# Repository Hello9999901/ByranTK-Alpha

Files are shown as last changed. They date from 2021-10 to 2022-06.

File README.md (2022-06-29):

# ByranTK-Alpha

# Note: New 3D Printed Version of the case added! First prototype working!!

*The ByranTK-Alpha is an 80 key custom mechanical keyboard, designed to be made with any material.*
<br>
<br>
*"All the keys you need and no more."*

### V1.1 is confirmed to be working with firmware from https://github.com/Hello9999901/zmk-config-btk-alpha

# What is it:
The ByranTK-Alpha is an ongoing open-source keyboard project. It is extremely simple and utilizes a nice!nano from Nice Keyboards as the MCU. The battery life is estimated to be around 3 months of continuous usage (varies extremely depending on battery capacity, tested with 500mah battery from Adafruit). The keyboard is designed in KiCAD and FreeCAD, with the renders made with Blender.

# Features:
 - ZMK Firmware
 - Pro Micro Form Factor *
 - Wireless First Design
 - Split Spacebar
 - Low Profile (relative to other keyboards)
 - Hotswap Sockets
 - South facing (supports cherry profile)
 - Exploded 75% (ish) layout
 - Highly Customizable

# Why?
Because nobody has done such thing yet. I have always wanted a simple-looking, customizable (software-wise and hardware-wise), exploded 75% layout keyboard. In addition, it had to be under a certain price point. I estimate for it to cost less than 100 dollars for all the parts and all the machining, though that is subject to change. If you want CNC alu, then that'll cost you a couple cold hard Benjamins (tldr; a lot).

# Image Gallery
(subject to change as design alters)
<div style="display: flex;">
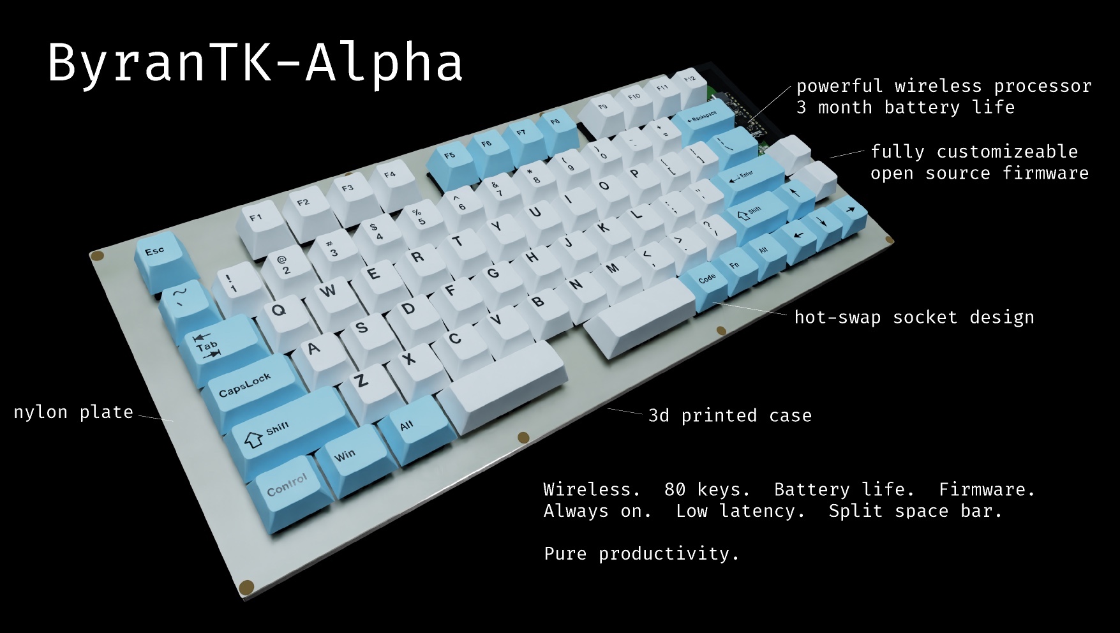
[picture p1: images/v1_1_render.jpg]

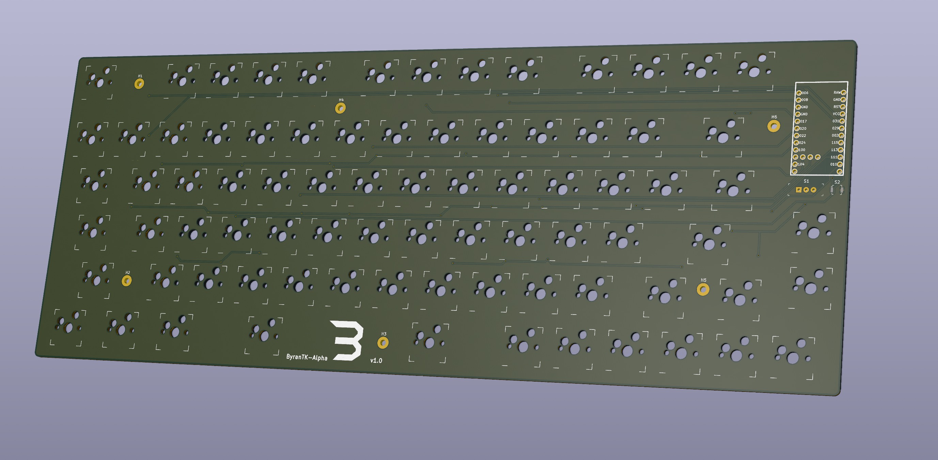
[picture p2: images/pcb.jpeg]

</div>

# Build Guide
### This build guide is very vague and will be improved on in the near future
### Parts:
> Note that these part links are only for reference. Some products can be found for cheaper (especially the hotswap sockets).

> The SPDT and SPST switches have specific footprints that match on the board. You can alter them if they're out of stock.

> You don't need to buy diodes if you are using SMT assembly. I used JLCPCB.
  - PCB
  - [Kailh Hotswap Sockets](https://shop.keyboard.io/products/kailh-hotswap-sockets-for-mx-style-keyswitches-x-25)
  - [Diodes (1N4148 SMT SOD-123)](https://www.adafruit.com/product/5099)
  - [SPDT Switch](https://www.adafruit.com/product/805)
  - [Battery (can be different capacity) with JST-PH 2 Pin Header](https://www.adafruit.com/product/1578)
  - [SPST Switch](https://www.adafruit.com/product/1489)
  - [JST-PH Right Angle Connector](https://www.adafruit.com/product/1769)
  - [Swiss Socket Headers (Female)](https://www.adafruit.com/product/3646)
  - [Swiss Socket Headers (Male)](https://www.adafruit.com/product/3647)

1. Order all the parts
   - I ordered everything off of JLCPCB, with SMT assembly for the diodes because I'm lazy. The pick and place/bom files are in the bom folder, ready for upload to JLCPCB. It is highly suggested you use SMT assembly because it is extremely cheap and saves a lot of time.
   - Apparantly, you can also get smt hotswap sockets assembled too, though I did not do that.
2. Solder it all together
   - Solder on the hotswap sockets and the nice!nano. This will take a while (perhaps an hour or two) depending on your soldering experience. Note that if you choose not to use SMT assembly on the PCB, the diodes will be very hard to solder. I socketed the nice!nano using Swiss machine pins off of Adafruit.
3. Build and flash the firmware onto the nice!nano
   - Build the firmware and put the nice!nano into bootloader (DFU) mode (short GND and RST twice in rapid succession). Drag the UF2 file into the nice!nano "storage device". The firmware can be made with my zmk-config directory.
4. Laser cut the case or 3D print
   - This step is pretty self explanatory. It's a sandwich design, so lasercut many pieces and adhere them together. The plate must be 1.5mm (+- 0.1mm). The rest can be any height as long as when everything is stacked together, it is taller than 15mm, and the height between the bottom of the plate and the top of the bottom pice is taller than 12mm.
   - Alternatively, you can 3D print the case. I decided to 3D print because it was faster to prototype. 2 file types, one split and one full depending on your bed size. It also looks really cool.
5. Put everything together
   - Glue it, screw it together, I don't really know. I screwed into a 3D printed case with some screws found in a bin of hope. Just make sure the entire thing fits. If you're that type of person, the more FLeX the better. Nylon should get you that. Plug in the battery (you might need to switch the battery wiring to make sure the GND goes into GND and RAW goes into RAW). You don't need screws to hold the PCB and plate together; the hotswap sockets and the plate should hold itself together. Get some 5mm foam and put it as dampener under the PCB. Make sure to keep the battery isolated when dampening so it doesn't short/blow up.
6. Use it
   - You've made it! Congrats! Customize the keymap, change the case material, it's all up to you. That's the beauty of open source hardware and software. I hope you enjoy the ByranTK-Alpha.

# License
Unless stated otherwise, the parts are licensed under the MIT License. Parts that are identified as (GPL) are licensed under the GPLv3 License.

\* The nice!nano v2 is used in this design. It has 3 extra pins in the center of the PCB, two of which the ByranTK-Alpha utilizes

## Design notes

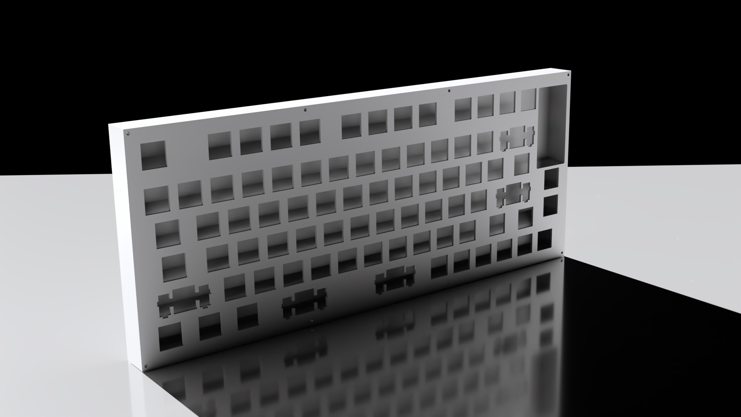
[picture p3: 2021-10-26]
images/case.jpeg

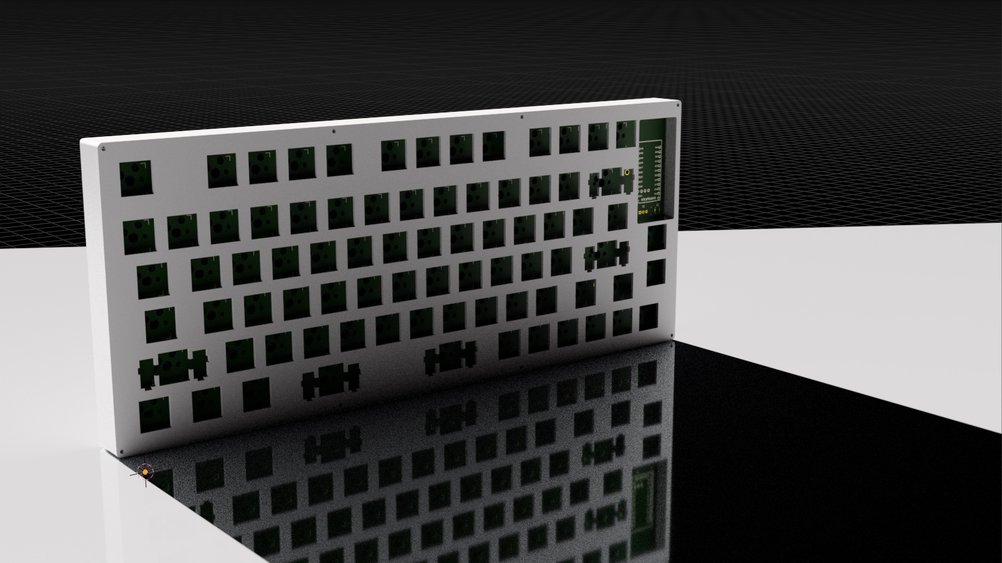
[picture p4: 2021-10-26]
images/caseWpcb.jpeg

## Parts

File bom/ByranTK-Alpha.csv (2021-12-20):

Comment | Designator | Footprint | LCSC
Battery | BT1
1N4148W | D1,D2,D3,D4,D5,D6,D7,D8,D9,D10,D11,D12,D13,D14,D15,D16,D17,D18,D19,D20,D21,D22,D23,D24,D25,D26,D27,D28,D29,D30,D31,D32,D33,D34,D35,D36,D37,D38,D39,D40,D41,D42,D43,D44,D45,D46,D47,D48,D49,D50,D51,D52,D53,D54,D55,D56,D57,D58,D59,D60,D61,D62,D63,D64,D65,D66,D67,D68,D69,D70,D71,D72,D73,D74,D75,D76,D77,D78,D79,D80 | Diode_SMD:D_SOD-123 | C81598
M2 Mounting_Hole | H1,H2,H3,H4,H5,H6 | MountingHole:MountingHole_2.2mm_M2_Pad_Via
JST-PH_SM4 | J1 | Connector_JST:JST_PH_S2B-PH-SM4-TB_1x02-1MP_P2.00mm_Horizontal
EG1218 | S1 | digikey-footprints:Switch_Slide_11.6x4mm_EG1218
6mm Slim Tactile Switch | S2 | Button_Switch_THT:SW_TH_Tactile_Omron_B3F-10xx
SW_Push | SW1,SW2,SW7,SW8,SW9,SW10,SW12,SW13,SW14,SW15,SW16,SW18,SW19,SW20,SW21,SW22,SW24,SW25,SW26,SW27,SW28,SW29,SW30,SW31,SW32,SW33,SW34,SW35,SW36,SW37,SW38,SW39,SW40,SW41,SW42,SW43,SW45,SW46,SW47,SW48,SW49,SW50,SW51,SW52,SW53,SW54,SW55,SW56,SW57,SW58,SW59,SW60,SW61,SW62,SW63,SW64,SW65,SW66,SW68,SW69,SW70,SW71,SW73,SW74,SW75,SW78,SW79,SW80 | MX_Only:MXOnly-1U-Hotswap
SW_Push | SW23,SW44 | MX_Only:MXOnly-2.75U-Hotswap
SW_Push | SW3,SW77 | MX_Only:MXOnly-1.5U-Hotswap
SW_Push | SW4,SW67 | MX_Only:MXOnly-1.75U-Hotswap
SW_Push | SW5,SW72 | MX_Only:MXOnly-2.25U-Hotswap
SW_Push | SW6,SW11,SW17 | MX_Only:MXOnly-1.25U-Hotswap
SW_Push | SW76 | MX_Only:MXOnly-2U-Hotswap
nice_nano | U1 | nice_nano:nice_nano

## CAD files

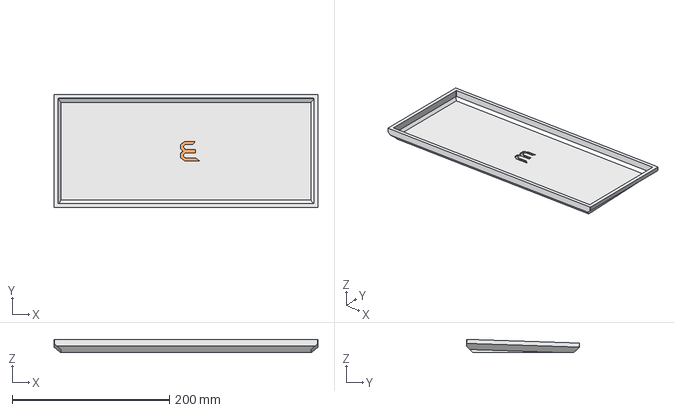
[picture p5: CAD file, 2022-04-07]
case/3D Print/Full Print.step
335.4 x 144.0 x 16.9 mm

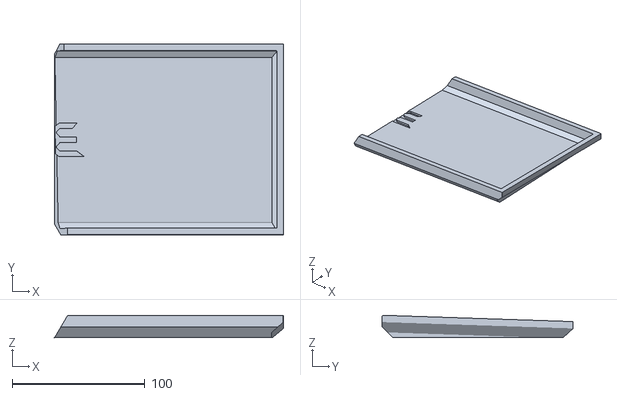
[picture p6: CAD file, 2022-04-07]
case/3D Print/Split Prints/cut_l.stl
172.5 x 144.0 x 16.9

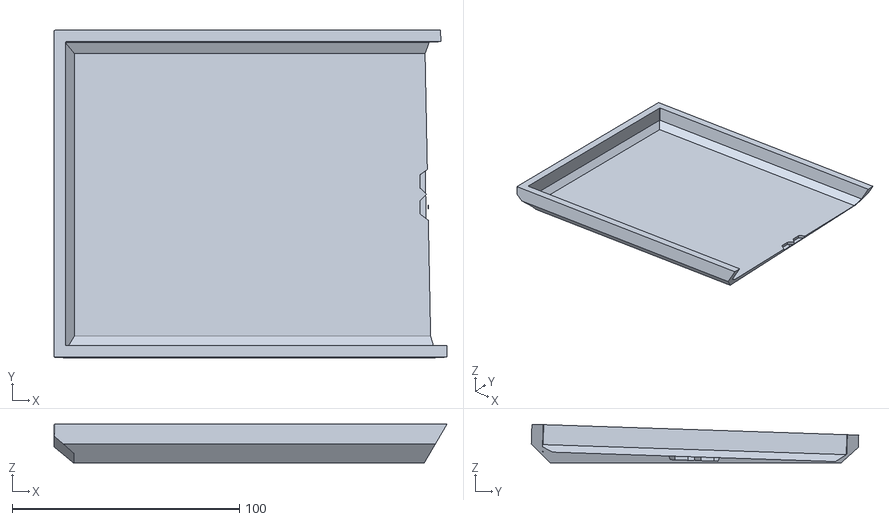
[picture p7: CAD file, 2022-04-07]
case/3D Print/Split Prints/cut_r.stl
172.8 x 144.0 x 16.9

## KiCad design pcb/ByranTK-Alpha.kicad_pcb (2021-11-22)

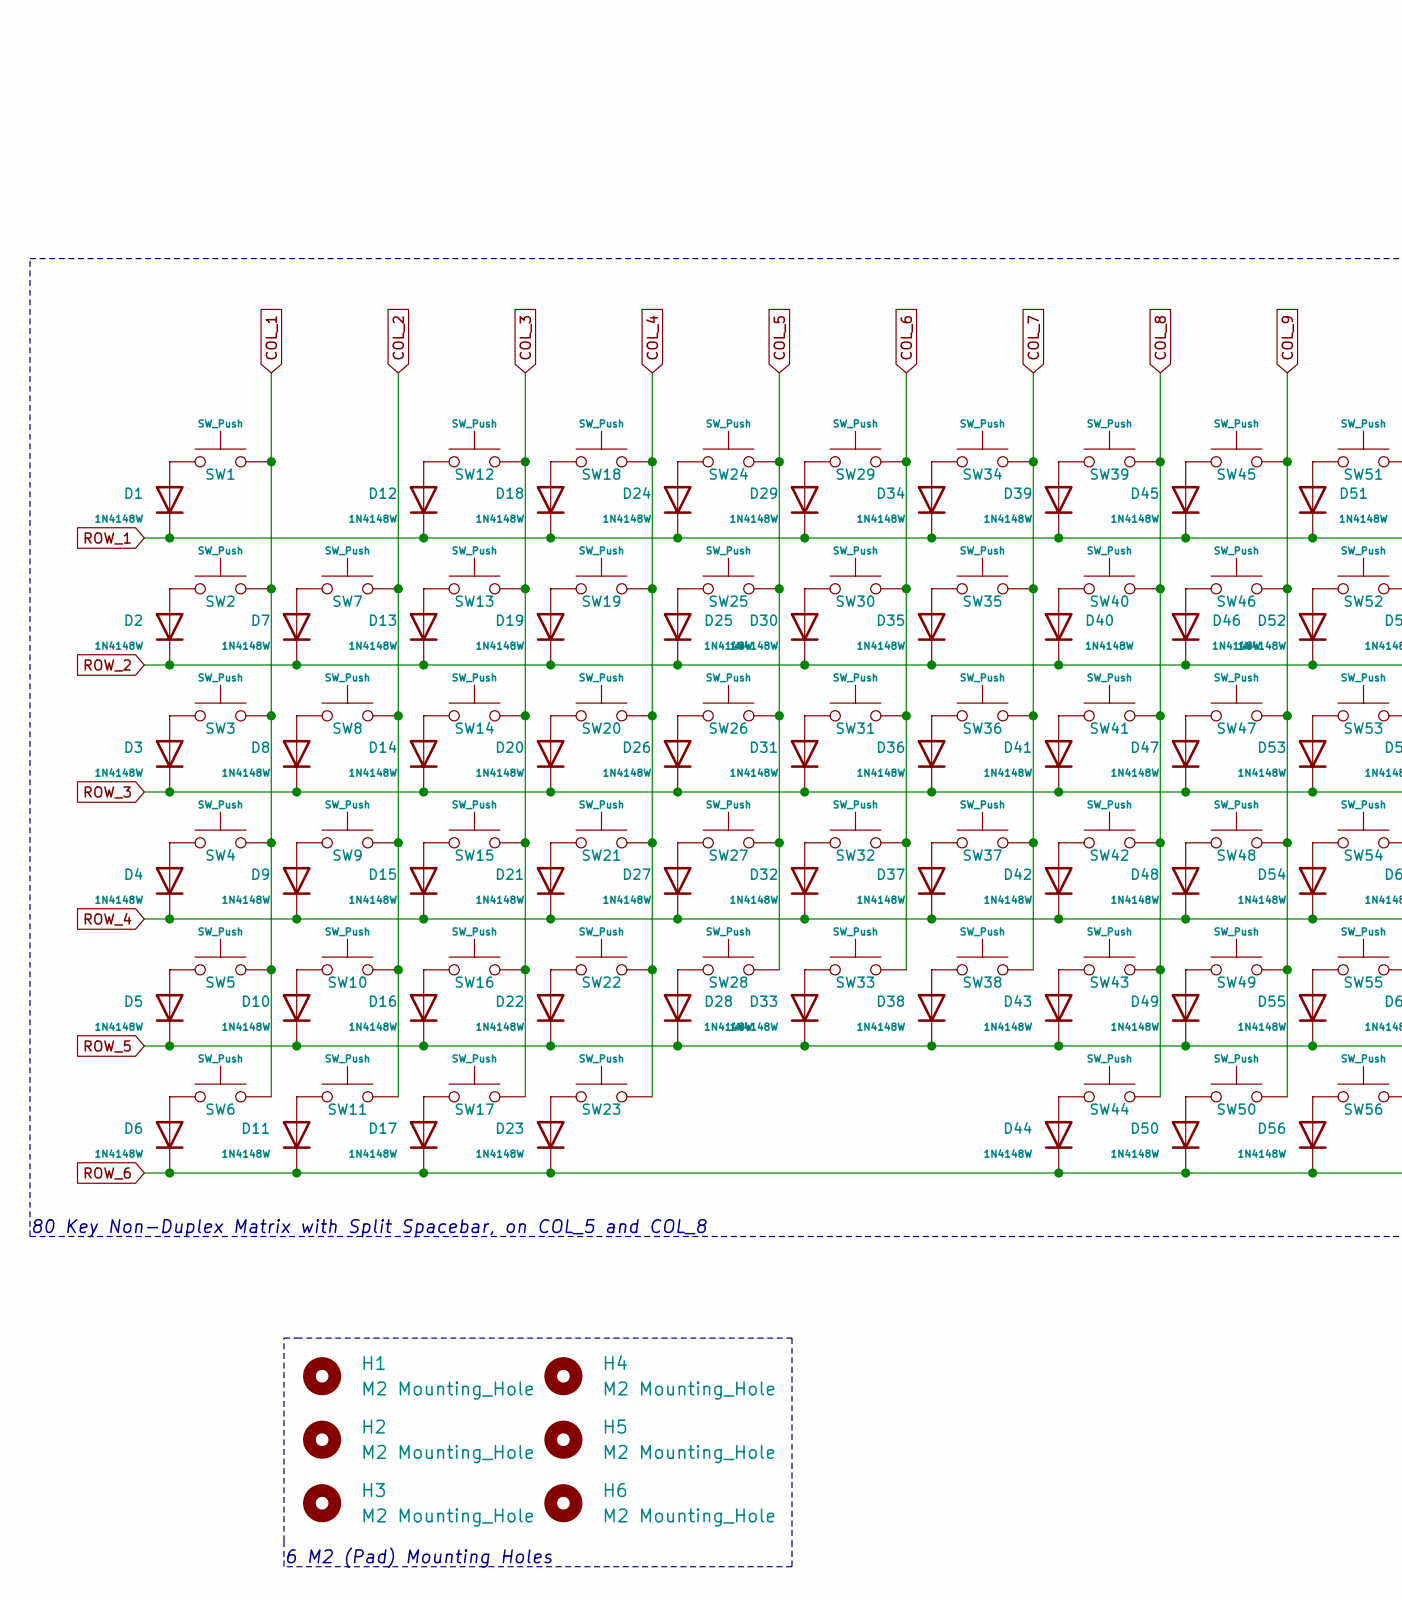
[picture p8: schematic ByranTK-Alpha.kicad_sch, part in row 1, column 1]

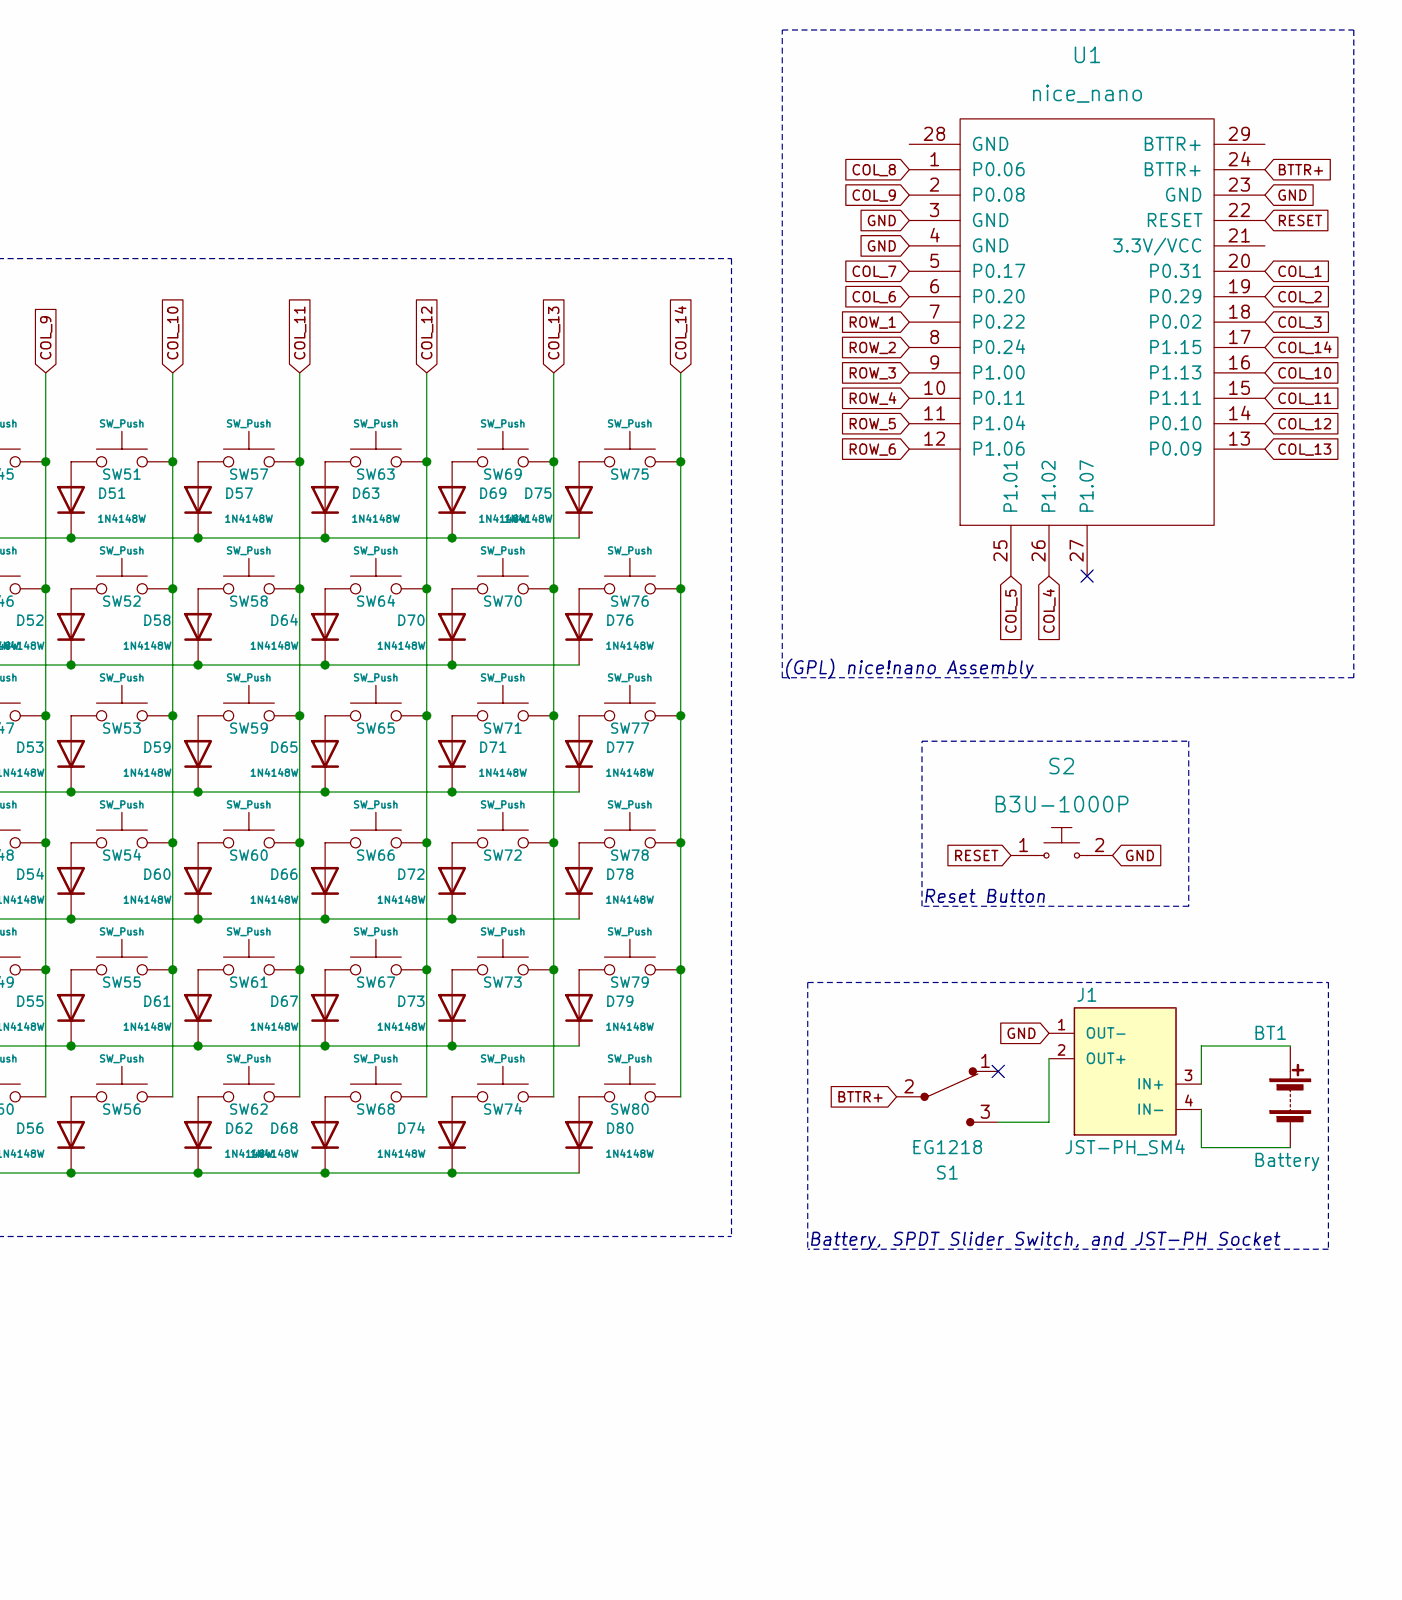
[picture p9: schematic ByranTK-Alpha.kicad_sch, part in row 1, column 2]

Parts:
BT1: Battery; ADAFRUIT_BAT_ID_1570_100mAh
D1, D2, D3, D4, D5, D6, D7, D8, D9, D10, D11, D12, D13, D14, D15, D16, D17, D18, D19, D20, D21, D22, D23, D24, D25, D26, D27, D28, D29, D30, D31, D32, D33, D34, D35, D36, D37, D38, D39, D40, D41, D42, D43, D44, D45, D46, D47, D48, D49, D50, D51, D52, D53, D54, D55, D56, D57, D58, D59, D60, D61, D62, D63, D64, D65, D66, D67, D68, D69, D70, D71, D72, D73, D74, D75, D76, D77, D78, D79, D80: 1N4148W; D_SOD-123
H1, H2, H3, H4, H5, H6: M2 Mounting_Hole; MountingHole_2.2mm_M2_Pad
J1: JST-PH_SM4; JST_PH_S2B-PH-SM4-TB_1x02-1MP_P2.00mm_Horizontal
S1: EG1218; Switch_Slide_11.6x4mm_EG1218; MPN EG1218; Digi-Key_PN EG1903-ND
S2: B3U-1000P; Switch_Tactile_SMD_B3U-1000P; MPN B3U-1000P; Digi-Key_PN SW1020CT-ND
SW1, SW2, SW7, SW8, SW9, SW10, SW12, SW13, SW14, SW15, SW16, SW18, SW19, SW20, SW21, SW22, SW24, SW25, SW26, SW27, SW28, SW29, SW30, SW31, SW32, SW33, SW34, SW35, SW36, SW37, SW38, SW39, SW40, SW41, SW42, SW43, SW45, SW46, SW47, SW48, SW49, SW50, SW51, SW52, SW53, SW54, SW55, SW56, SW57, SW58, SW59, SW60, SW61, SW62, SW63, SW64, SW65, SW66, SW68, SW69, SW70, SW71, SW73, SW74, SW75, SW78, SW79, SW80: SW_Push; MXOnly-1U-Hotswap
SW3, SW77: SW_Push; MXOnly-1.5U-Hotswap
SW4, SW67: SW_Push; MXOnly-1.75U-Hotswap
SW5, SW72: SW_Push; MXOnly-2.25U-Hotswap
SW6, SW11, SW17: SW_Push; MXOnly-1.25U-Hotswap
SW23, SW44: SW_Push; MXOnly-2.75U-Hotswap
SW76: SW_Push; MXOnly-2U-Hotswap
U1: nice_nano

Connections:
BTTR+: S1.2, U1.24 (BTTR+)
COL_1: SW1.2, SW2.2, SW3.2, SW4.2, SW5.2, SW6.2, U1.20 (P0.31)
COL_2: SW7.2, SW8.2, SW9.2, SW10.2, SW11.2, U1.19 (P0.29)
COL_3: SW12.2, SW13.2, SW14.2, SW15.2, SW16.2, SW17.2, U1.18 (P0.02)
COL_4: SW18.2, SW19.2, SW20.2, SW21.2, SW22.2, SW23.2, U1.26 (P1.02)
COL_5: SW24.2, SW25.2, SW26.2, SW27.2, SW28.2, U1.25 (P1.01)
COL_6: SW29.2, SW30.2, SW31.2, SW32.2, SW33.2, U1.6 (P0.20)
COL_7: SW34.2, SW35.2, SW36.2, SW37.2, SW38.2, U1.5 (P0.17)
COL_8: SW39.2, SW40.2, SW41.2, SW42.2, SW43.2, SW44.2, U1.1 (P0.06)
COL_9: SW45.2, SW46.2, SW47.2, SW48.2, SW49.2, SW50.2, U1.2 (P0.08)
COL_10: SW51.2, SW52.2, SW53.2, SW54.2, SW55.2, SW56.2, U1.16 (P1.13)
COL_11: SW57.2, SW58.2, SW59.2, SW60.2, SW61.2, SW62.2, U1.15 (P1.11)
COL_12: SW63.2, SW64.2, SW65.2, SW66.2, SW67.2, SW68.2, U1.14 (P0.10)
COL_13: SW69.2, SW70.2, SW71.2, SW72.2, SW73.2, SW74.2, U1.13 (P0.09)
COL_14: SW75.2, SW76.2, SW77.2, SW78.2, SW79.2, SW80.2, U1.17 (P1.15)
GND: J1.1 (OUT-), S2.2, U1.3 (GND), U1.4 (GND), U1.23 (GND)
unnamed: D1.2 (A), SW1.1
unnamed: D2.2 (A), SW2.1
unnamed: D3.2 (A), SW3.1
unnamed: D4.2 (A), SW4.1
unnamed: D5.2 (A), SW5.1
unnamed: D6.2 (A), SW6.1
unnamed: D7.2 (A), SW7.1
unnamed: D8.2 (A), SW8.1
unnamed: D9.2 (A), SW9.1
unnamed: D10.2 (A), SW10.1
unnamed: D11.2 (A), SW11.1
unnamed: D12.2 (A), SW12.1
unnamed: D13.2 (A), SW13.1
unnamed: D14.2 (A), SW14.1
unnamed: D15.2 (A), SW15.1
unnamed: D16.2 (A), SW16.1
unnamed: D17.2 (A), SW17.1
unnamed: D18.2 (A), SW18.1
unnamed: D19.2 (A), SW19.1
unnamed: D20.2 (A), SW20.1
unnamed: D21.2 (A), SW21.1
unnamed: D22.2 (A), SW22.1
unnamed: D23.2 (A), SW23.1
unnamed: D24.2 (A), SW24.1
unnamed: D25.2 (A), SW25.1
unnamed: D26.2 (A), SW26.1
unnamed: D27.2 (A), SW27.1
unnamed: D28.2 (A), SW28.1
unnamed: D29.2 (A), SW29.1
unnamed: D30.2 (A), SW30.1
unnamed: D31.2 (A), SW31.1
unnamed: D32.2 (A), SW32.1
unnamed: D33.2 (A), SW33.1
unnamed: D34.2 (A), SW34.1
unnamed: D35.2 (A), SW35.1
unnamed: D36.2 (A), SW36.1
unnamed: D37.2 (A), SW37.1
unnamed: D38.2 (A), SW38.1
unnamed: D39.2 (A), SW39.1
unnamed: D40.2 (A), SW40.1
unnamed: D41.2 (A), SW41.1
unnamed: D42.2 (A), SW42.1
unnamed: D43.2 (A), SW43.1
unnamed: D44.2 (A), SW44.1
unnamed: D45.2 (A), SW45.1
unnamed: D46.2 (A), SW46.1
unnamed: D47.2 (A), SW47.1
unnamed: D48.2 (A), SW48.1
unnamed: D49.2 (A), SW49.1
unnamed: D50.2 (A), SW50.1
unnamed: D51.2 (A), SW51.1
unnamed: D52.2 (A), SW52.1
unnamed: D53.2 (A), SW53.1
unnamed: D54.2 (A), SW54.1
unnamed: D55.2 (A), SW55.1
unnamed: D56.2 (A), SW56.1
unnamed: D57.2 (A), SW57.1
unnamed: D58.2 (A), SW58.1
unnamed: D59.2 (A), SW59.1
unnamed: D60.2 (A), SW60.1
unnamed: D61.2 (A), SW61.1
unnamed: D62.2 (A), SW62.1
unnamed: D63.2 (A), SW63.1
unnamed: D64.2 (A), SW64.1
unnamed: D65.2 (A), SW65.1
unnamed: D66.2 (A), SW66.1
unnamed: D67.2 (A), SW67.1
unnamed: D68.2 (A), SW68.1
unnamed: D69.2 (A), SW69.1
unnamed: D70.2 (A), SW70.1
unnamed: D71.2 (A), SW71.1
unnamed: D72.2 (A), SW72.1
unnamed: D73.2 (A), SW73.1
unnamed: D74.2 (A), SW74.1
unnamed: D75.2 (A), SW75.1
unnamed: D76.2 (A), SW76.1
unnamed: D77.2 (A), SW77.1
unnamed: D78.2 (A), SW78.1
unnamed: D79.2 (A), SW79.1
unnamed: D80.2 (A), SW80.1
unnamed: J1.2 (OUT+), S1.3
RESET: S2.1, U1.22 (RESET)
ROW_1: D1.1 (K), D12.1 (K), D18.1 (K), D24.1 (K), D29.1 (K), D34.1 (K), D39.1 (K), D45.1 (K), D51.1 (K), D57.1 (K), D63.1 (K), D69.1 (K), D75.1 (K), U1.7 (P0.22)
ROW_2: D2.1 (K), D7.1 (K), D13.1 (K), D19.1 (K), D25.1 (K), D30.1 (K), D35.1 (K), D40.1 (K), D46.1 (K), D52.1 (K), D58.1 (K), D64.1 (K), D70.1 (K), D76.1 (K), U1.8 (P0.24)
ROW_3: D3.1 (K), D8.1 (K), D14.1 (K), D20.1 (K), D26.1 (K), D31.1 (K), D36.1 (K), D41.1 (K), D47.1 (K), D53.1 (K), D59.1 (K), D65.1 (K), D71.1 (K), D77.1 (K), U1.9 (P1.00)
ROW_4: D4.1 (K), D9.1 (K), D15.1 (K), D21.1 (K), D27.1 (K), D32.1 (K), D37.1 (K), D42.1 (K), D48.1 (K), D54.1 (K), D60.1 (K), D66.1 (K), D72.1 (K), D78.1 (K), U1.10 (P0.11)
ROW_5: D5.1 (K), D10.1 (K), D16.1 (K), D22.1 (K), D28.1 (K), D33.1 (K), D38.1 (K), D43.1 (K), D49.1 (K), D55.1 (K), D61.1 (K), D67.1 (K), D73.1 (K), D79.1 (K), U1.11 (P1.04)
ROW_6: D6.1 (K), D11.1 (K), D17.1 (K), D23.1 (K), D44.1 (K), D50.1 (K), D56.1 (K), D62.1 (K), D68.1 (K), D74.1 (K), D80.1 (K), U1.12 (P1.06)

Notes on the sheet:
80 Key Non-Duplex Matrix with Split Spacebar, on COL_5 and COL_8
6 M2 (Pad) Mounting Holes
(GPL) nice!nano Assembly
Battery, SPDT Slider Switch, and JST-PH Socket
Reset Button

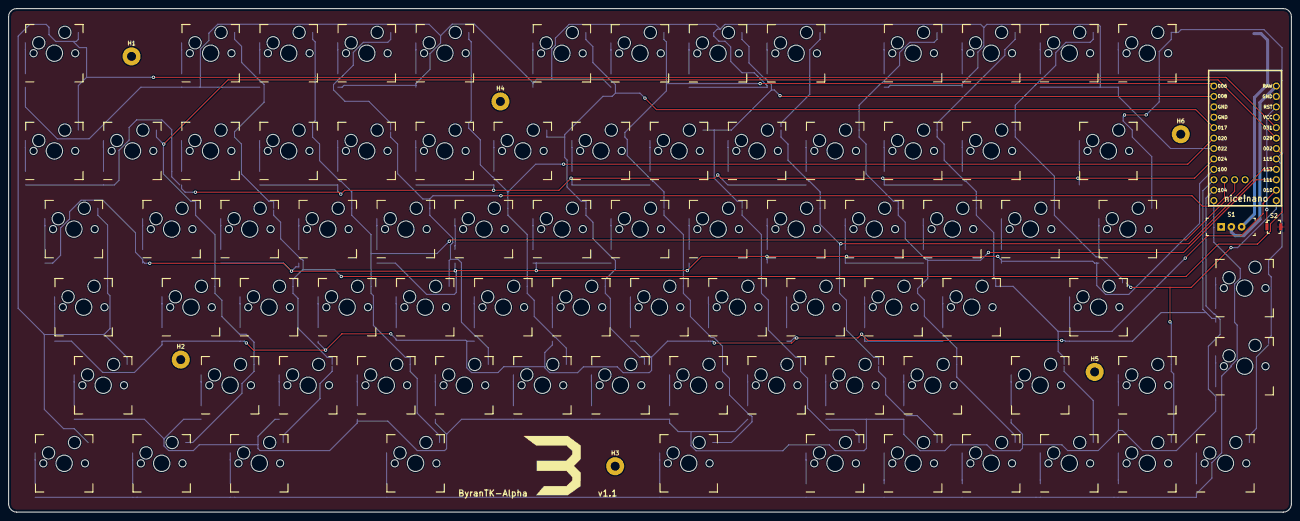
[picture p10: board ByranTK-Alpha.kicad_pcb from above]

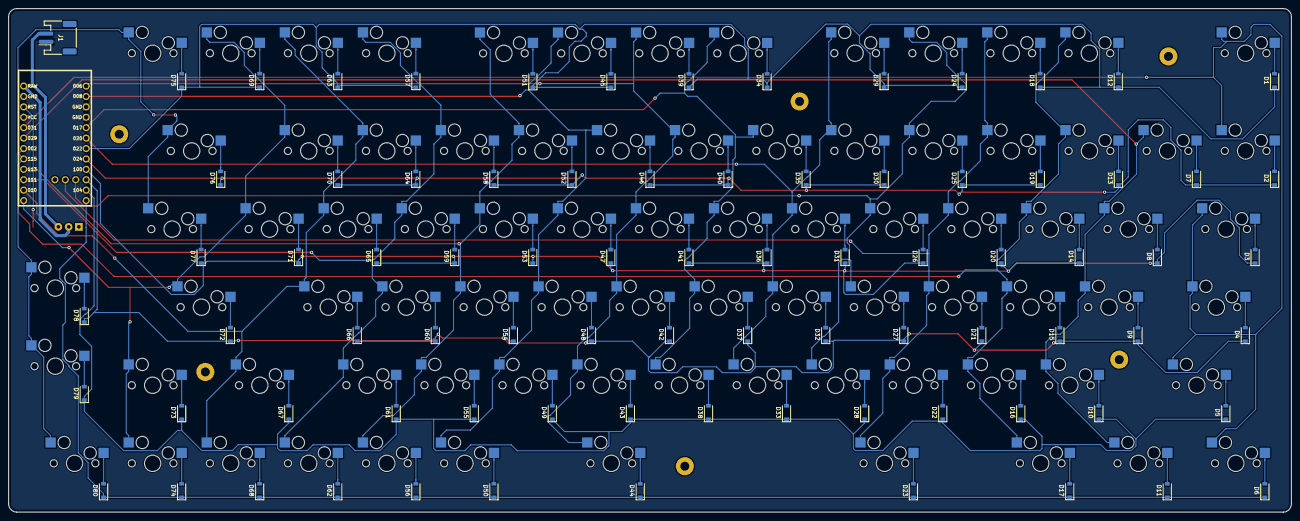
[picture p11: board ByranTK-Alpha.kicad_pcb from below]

Board: 2 copper layers, 313.0 x 122.9 mm, 171 parts (82 on the bottom side), 104 nets.

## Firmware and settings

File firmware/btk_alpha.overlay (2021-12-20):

#include <dt-bindings/zmk/matrix_transform.h>

/ {
    chosen {
        zmk,kscan = &kscan0;
        zmk,matrix_transform = &default_transform;
    };

    default_transform: keymap_transform_0 {
        compatible = "zmk,matrix-transform";
        columns = <14>;
        rows = <6>;
        map = <
    RC(0,0)          RC(0,2) RC(0,3) RC(0,4) RC(0,5)    RC(0,6) RC(0,7) RC(0,8) RC(0,9)      RC(0,10) RC(0,11) RC(0,12) RC(0,13)
    RC(1,0)  RC(1,1) RC(1,2) RC(1,3) RC(1,4) RC(1,5) RC(1,6) RC(1,7) RC(1,8) RC(1,9) RC(1,10) RC(1,11) RC(1,12)     RC(1,13)
    RC(2,0)    RC(2,1) RC(2,2) RC(2,3) RC(2,4) RC(2,5) RC(2,6) RC(2,7) RC(2,8) RC(2,9) RC(2,10) RC(2,11) RC(2,12)   RC(2,13)
    RC(3,0)     RC(3,1) RC(3,2) RC(3,3) RC(3,4) RC(3,5) RC(3,6) RC(3,7) RC(3,8) RC(3,9) RC(3,10) RC(3,11)      RC(3,12)       RC(3, 13)
    RC(4,0)       RC(4,1) RC(4,2) RC(4,3) RC(4,4) RC(4,5) RC(4,6) RC(4,7) RC(4,8) RC(4,9) RC(4,10)    RC(4,11)       RC(4,12) RC(4,13)
    RC(5,0)    RC(5,1)   RC(5,2)           RC(5,3)              RC(5,7)     RC(5,8)    RC(5,9)  RC(5,10)    RC(5,11) RC(5,12) RC(5,13)
        >;
    };
    kscan0: kscan_0 {
        compatible = "zmk,kscan-gpio-matrix";
        label = "KSCAN";
        diode-direction = "col2row";

        col-gpios
            = <&pro_micro 21 GPIO_ACTIVE_HIGH> //COL_1  D21
            , <&pro_micro 20 GPIO_ACTIVE_HIGH> //COL_2  D20
            , <&pro_micro 19 GPIO_ACTIVE_HIGH> //COL_3  D19
            , <&gpio1 2 GPIO_ACTIVE_HIGH>      //COL_4  P1.02
            , <&gpio1 1 GPIO_ACTIVE_HIGH>      //COL_5  P1.01
            , <&pro_micro 3 GPIO_ACTIVE_HIGH>  //COL_6  D3
            , <&pro_micro 2 GPIO_ACTIVE_HIGH>  //COL_7  D2
            , <&pro_micro 1 GPIO_ACTIVE_HIGH>  //COL_8  D1
            , <&pro_micro 0 GPIO_ACTIVE_HIGH> //COL_9   D0
            , <&pro_micro 15 GPIO_ACTIVE_HIGH> //COL_10 D15
            , <&pro_micro 14 GPIO_ACTIVE_HIGH> //COL_11 D14
            , <&pro_micro 16 GPIO_ACTIVE_HIGH> //COL_12 D16
            , <&pro_micro 10 GPIO_ACTIVE_HIGH> //COL_13 D10
            , <&pro_micro 18 GPIO_ACTIVE_HIGH> //COL_14 D18
            ;

        row-gpios
            = <&pro_micro 4 (GPIO_ACTIVE_HIGH | GPIO_PULL_DOWN)> //ROW_1 D4
            , <&pro_micro 5 (GPIO_ACTIVE_HIGH | GPIO_PULL_DOWN)> //ROW_2 D5
            , <&pro_micro 6 (GPIO_ACTIVE_HIGH | GPIO_PULL_DOWN)> //ROW_3 D6
            , <&pro_micro 7 (GPIO_ACTIVE_HIGH | GPIO_PULL_DOWN)> //ROW_4 D7
            , <&pro_micro 8 (GPIO_ACTIVE_HIGH | GPIO_PULL_DOWN)> //ROW_5 D8
            , <&pro_micro 9 (GPIO_ACTIVE_HIGH | GPIO_PULL_DOWN)> //ROW_6 D9
            ;
    };
};

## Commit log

2021-09-12 pcb upload
    [ByranTK-Alpha.kicad_pcb, ByranTK-Alpha.kicad_sch, pcb-ByranTK-Alpha.step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]
2021-11-22 revision 1.1
    [ByranTK-Alpha.kicad_pcb]
2021-12-19 updated to v1.1
    [ByranTK-Alpha.kicad_sch, pcb.FCStd]
2021-12-19 added bom and stuff
2021-12-20 added case dxf files
    [bottom.dxf, plate.dxf, sandwich.dxf]
2021-12-20 added pick and place/bom/ibom
    [ByranTK-Alpha.csv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]
2021-12-23 updated case files (switched ai to dxf, sorry!) will convert back to dxf later.
    [bottom.dxf, plate.dxf, sandwich.dxf]
2022-05-23 updated to kicad 6.99 (7)
    [ByranTK-Alpha.kicad_sch]

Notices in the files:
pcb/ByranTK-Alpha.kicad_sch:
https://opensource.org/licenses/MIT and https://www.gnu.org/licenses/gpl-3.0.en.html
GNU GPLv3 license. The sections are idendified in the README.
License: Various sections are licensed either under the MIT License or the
